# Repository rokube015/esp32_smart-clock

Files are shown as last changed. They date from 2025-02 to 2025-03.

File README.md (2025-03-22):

# ESP32-smart-clock

This repository provides firmware and PCB design for a clock with environmental monitoring project using the ESP-IDF framework.

## Features
- CO2, temperature, humidity and atmosphere pressure monitoring.
- Custom PCB design for the project.
  
 
## Prerequisites

### Software Requirements
- ESP-IDF version 5.3.1 or later
- Python 3.x
## Setup
1. **Install ESP-IDF**: Follow the [ESP-IDF Getting Started Guide](https://docs.espressif.com/projects/esp-idf/en/latest/esp32/get-started/index.html).
2. **Clone the Repository**:
   ```bash
   git clone https://github.com/rokube015/esp32_smart-clock.git
## License
This project is licensed under the [Apache License 2.0](./LICENSE).

### Third-Party Licenses

This project utilizes the following third-party libraries:

- **[ESP-IDF](https://github.com/espressif/esp-idf)** - Licensed under the Apache License 2.0
- **[FreeRTOS](https://github.com/FreeRTOS/FreeRTOS)** - Licensed under the MIT License
- **[LovyanGFX](https://github.com/lovyan03/LovyanGFX)** - Licensed under the MIT License

Each library is subject to its own license terms. Please refer to the respective repositories for more information.
## Contributing
Contributions are welcome!
Please use the Issues tab to report bugs or suggest features, and feel free to submit pull requests.

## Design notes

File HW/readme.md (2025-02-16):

# Hardware Information

This folder contains PCB design files for the ESP32 Smart Clock.

## PCB Folder
The `PCB/` folder contains KiCad project files for the ESP32 Smart Clock.

## Files Description
- **PCB_layout.pdf**: PCB design layout.
- **schematic.pdf**: Circuit schematic diagram.
- **Bom.csv**: List of components required to build the SmartClock.

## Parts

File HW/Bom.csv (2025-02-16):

Reference | Value | Datasheet | Footprint | Qty | DNP
C1,C5 | 10uF | ~ | Capacitor_SMD:C_0603_1608Metric_Pad1.08x0.95mm_HandSolder | 2
C2,C12 | 22uF | ~ | Capacitor_SMD:C_0603_1608Metric_Pad1.08x0.95mm_HandSolder | 2
C3,C13,C15,C16,C18,C19,C20,C21 | 4.7uF | ~ | Capacitor_SMD:C_0603_1608Metric_Pad1.08x0.95mm_HandSolder | 8
C4 | 0.1uF | ~ | Capacitor_SMD:C_0805_2012Metric_Pad1.18x1.45mm_HandSolder | 1
C6,C11 | 0.01uF | ~ | Capacitor_SMD:C_0603_1608Metric_Pad1.08x0.95mm_HandSolder | 2
C7,C8 | 15pF | ~ | Capacitor_SMD:C_0603_1608Metric_Pad1.08x0.95mm_HandSolder | 2
C9,C10,C17,C22 | 1uF | ~ | Capacitor_SMD:C_0603_1608Metric_Pad1.08x0.95mm_HandSolder | 4
D1,D5,D6 | LED | ~ | LED_SMD:LED_0603_1608Metric_Pad1.05x0.95mm_HandSolder | 3
D2,D3,D7,D8,D9 | RB161MM-20 | ~ | Diode_SMD:D_SOD-123 | 5
J1 | USB4105-GF-A | https://www.usb.org/sites/default/files/documents/usb_type-c.zip | mylib:USB-C31-S-VT-CS4-BK-PP-TR | 1
J4 | Micro_SD_Card_Det_Hirose_DM3AT | https://www.hirose.com/product/en/download_file/key_name/DM3/category/Catalog/doc_file_id/49662/?item_id=195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 | Connector_Card:microSD_HC_Hirose_DM3AT-SF-PEJM5 | 1
L1 | 10uH | ~ | mylib:AMP10420ED | 1
Q2 | SI1308EDL-T1-GE3 | https://www.onsemi.com/pub/Collateral/BSS138-D.PDF | Package_TO_SOT_SMD:SOT-323_SC-70_Handsoldering | 1
R1,R2 | 5.1K | ~ | Resistor_SMD:R_1206_3216Metric_Pad1.30x1.75mm_HandSolder | 2
R3 | 0.47 | ~ | Resistor_SMD:R_1206_3216Metric_Pad1.30x1.75mm_HandSolder | 1
R4,R5,R7,R9,R10,R11,R14,R15 | 10K | ~ | Resistor_SMD:R_1206_3216Metric_Pad1.30x1.75mm_HandSolder | 8
R6 | 3 | ~ | Resistor_SMD:R_1206_3216Metric_Pad1.30x1.75mm_HandSolder | 1
R8 | 50K | ~ | Resistor_SMD:R_1206_3216Metric_Pad1.30x1.75mm_HandSolder | 1
SW1 | ssss213202 | ~ | mylib:SSSS213202 | 1
SW2,SW3,SW4 | SKRPACE010 | ~ | mylib:SKRPACE010 | 3
TP1,TP11 | GND | ~ | TestPoint:TestPoint_THTPad_1.0x1.0mm_Drill0.5mm | 2
TP2 | BUSY | ~ | TestPoint:TestPoint_THTPad_D1.0mm_Drill0.5mm | 1
TP3 | RST | ~ | TestPoint:TestPoint_THTPad_D1.0mm_Drill0.5mm | 1
TP4 | D/C | ~ | TestPoint:TestPoint_THTPad_D1.0mm_Drill0.5mm | 1
TP5 | CS | ~ | TestPoint:TestPoint_THTPad_D1.0mm_Drill0.5mm | 1
TP6 | SCK | ~ | TestPoint:TestPoint_THTPad_D1.0mm_Drill0.5mm | 1
TP7 | MOSI | ~ | TestPoint:TestPoint_THTPad_D1.0mm_Drill0.5mm | 1
TP8 | SCL | ~ | TestPoint:TestPoint_THTPad_D1.0mm_Drill0.5mm | 1
TP9 | SDA | ~ | TestPoint:TestPoint_THTPad_D1.0mm_Drill0.5mm | 1
TP10 | 3V3 | ~ | TestPoint:TestPoint_THTPad_D1.0mm_Drill0.5mm | 1
U1 | BME280 |  | mylib:BME280_SwitchScience | 1
U2 | E-Paper 4.26inch, 800x480 | https://www.waveshare.com/4.26inch-e-paper.htm | XF2M-2415-1A:CONN_XF2M-2415-1A_OMR | 1
U4 | ESP32-S3-WROOM-1 | https://www.espressif.com/sites/default/files/documentation/esp32-s3-wroom-1_wroom-1u_datasheet_en.pdf | mylib:ESP32-S3-WROOM-1 | 1
U5 | SCD40 |  | mylib:SCD40_Conta | 1
U6 | AZ1117CH-3_3TRG1 |  | Package_TO_SOT_SMD:SOT-223 | 1
U7 | TPS2065DDBVR | TPS2065DDBVR | Package_TO_SOT_SMD:SOT-23-5 | 1
Y1 | FC-135 | ~ | mylib:FC-135 | 1
- | Card stand | https://www.amazon.co.jp/gp/product/B0BGGFBQXZ/ref=ppx_yo_dt_b_search_asin_title?ie=UTF8&psc=1 | - | 1
- | Thermal Conductive Silicone Pads | https://www.amazon.co.jp/gp/product/B07RW81T8W/ref=ppx_yo_dt_b_search_asin_title?ie=UTF8&th=1 | - | 1

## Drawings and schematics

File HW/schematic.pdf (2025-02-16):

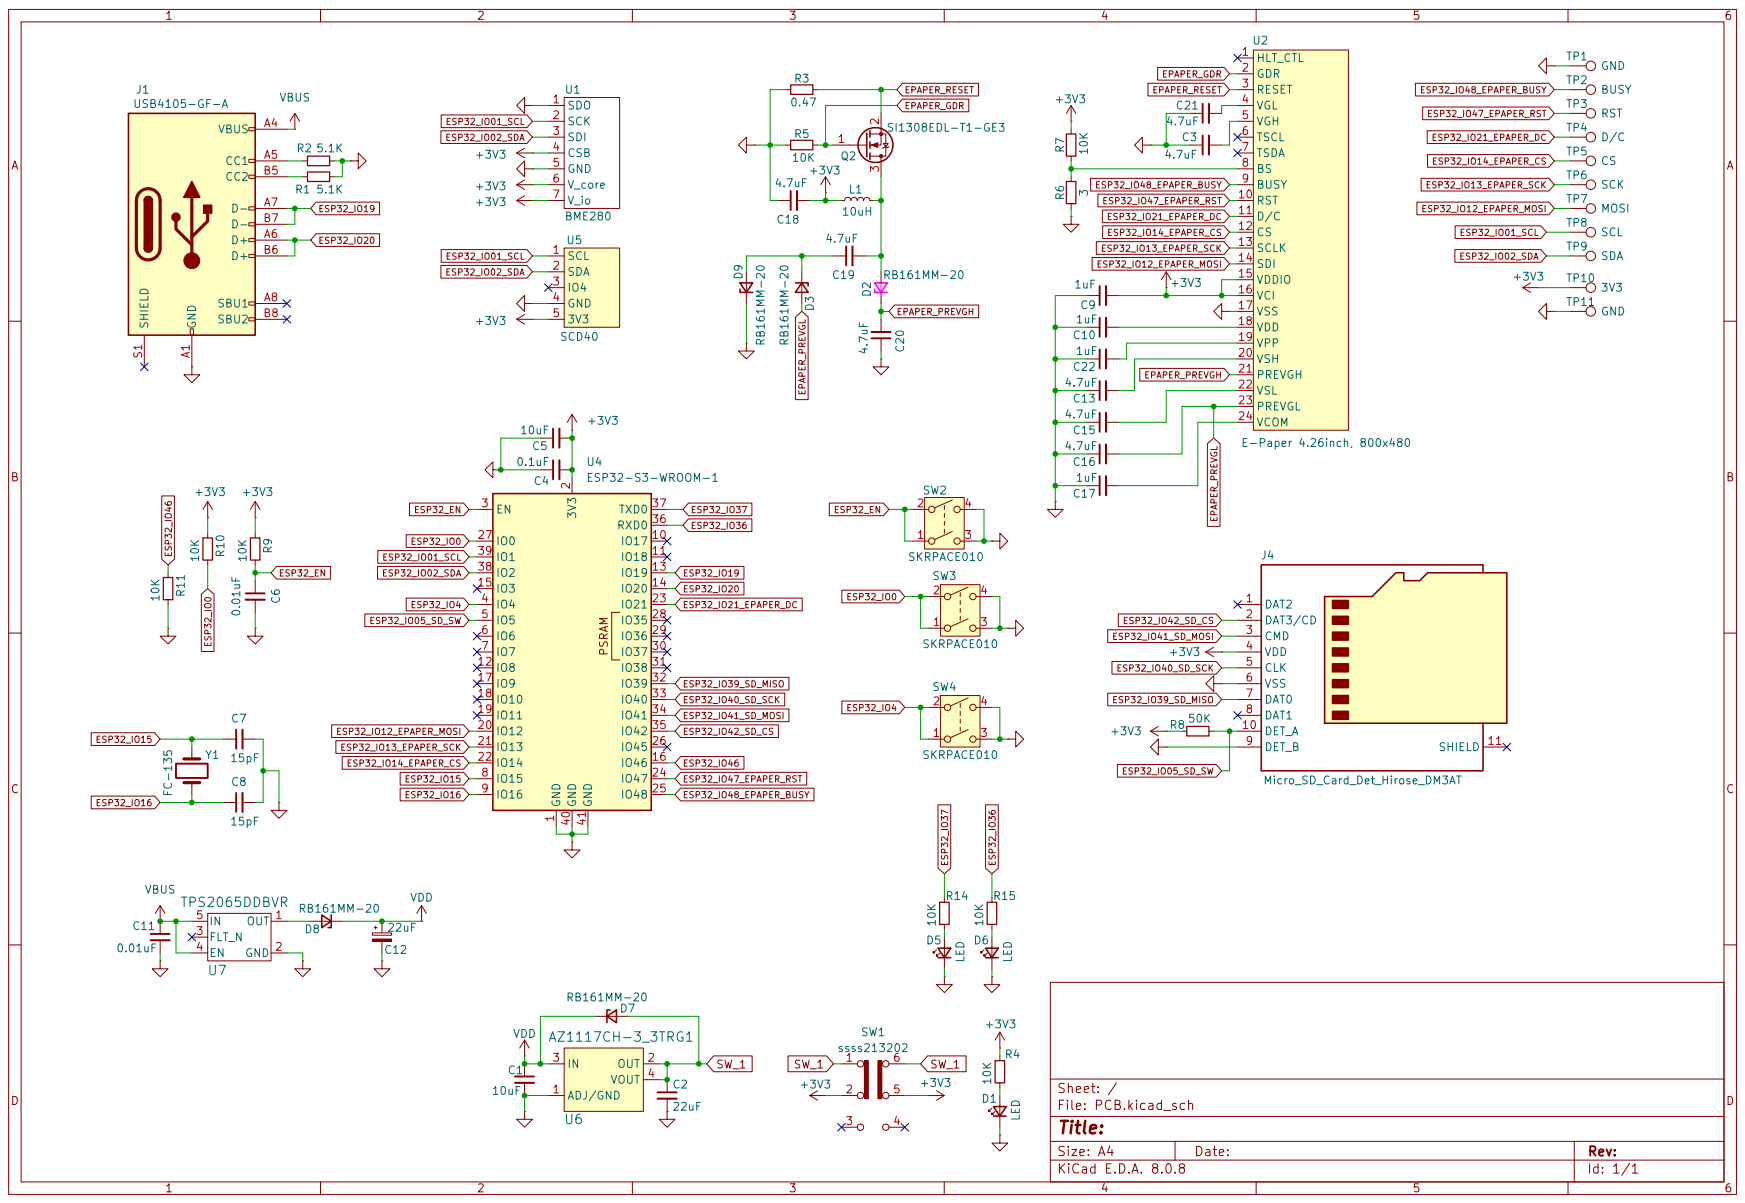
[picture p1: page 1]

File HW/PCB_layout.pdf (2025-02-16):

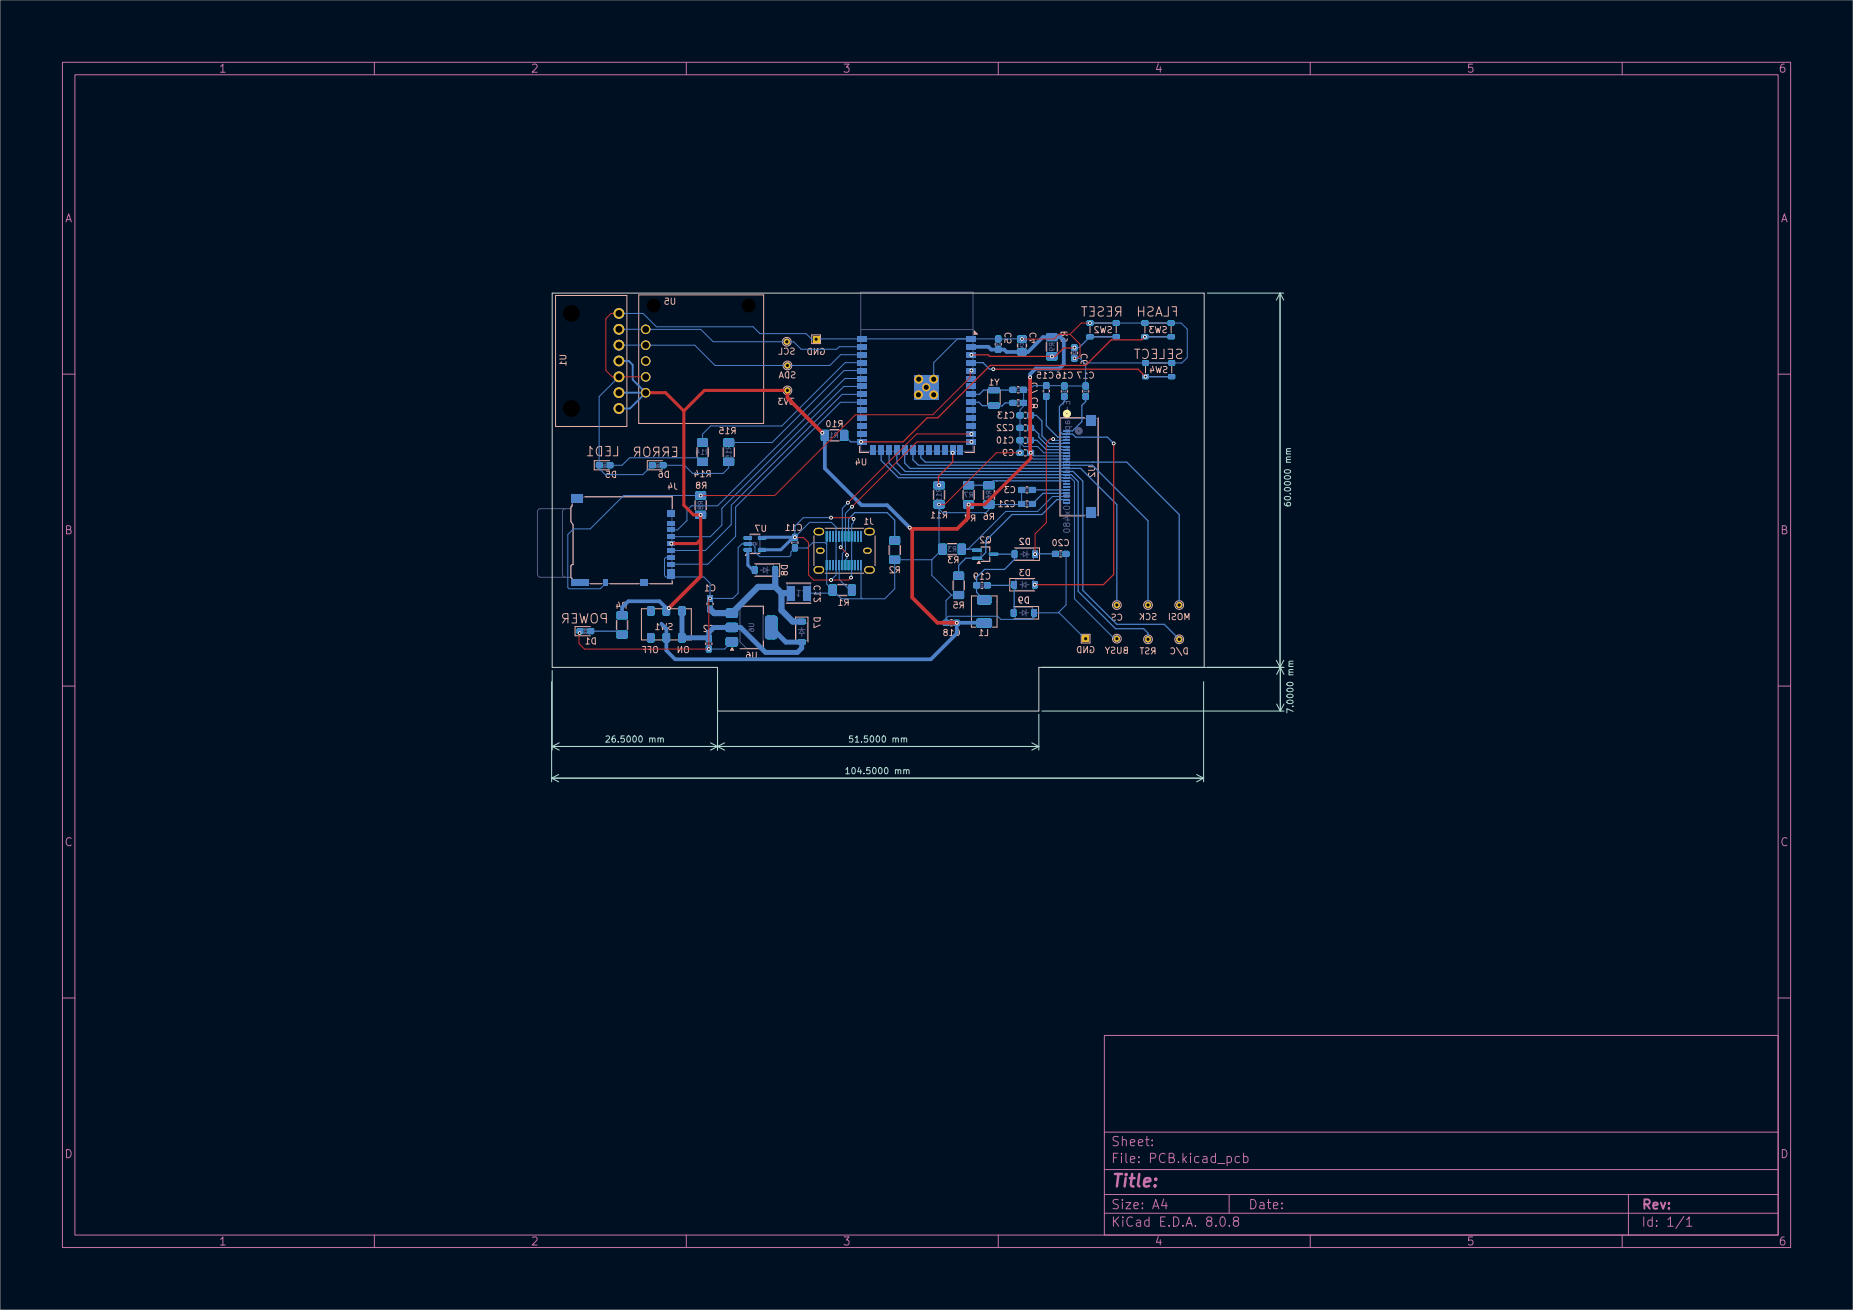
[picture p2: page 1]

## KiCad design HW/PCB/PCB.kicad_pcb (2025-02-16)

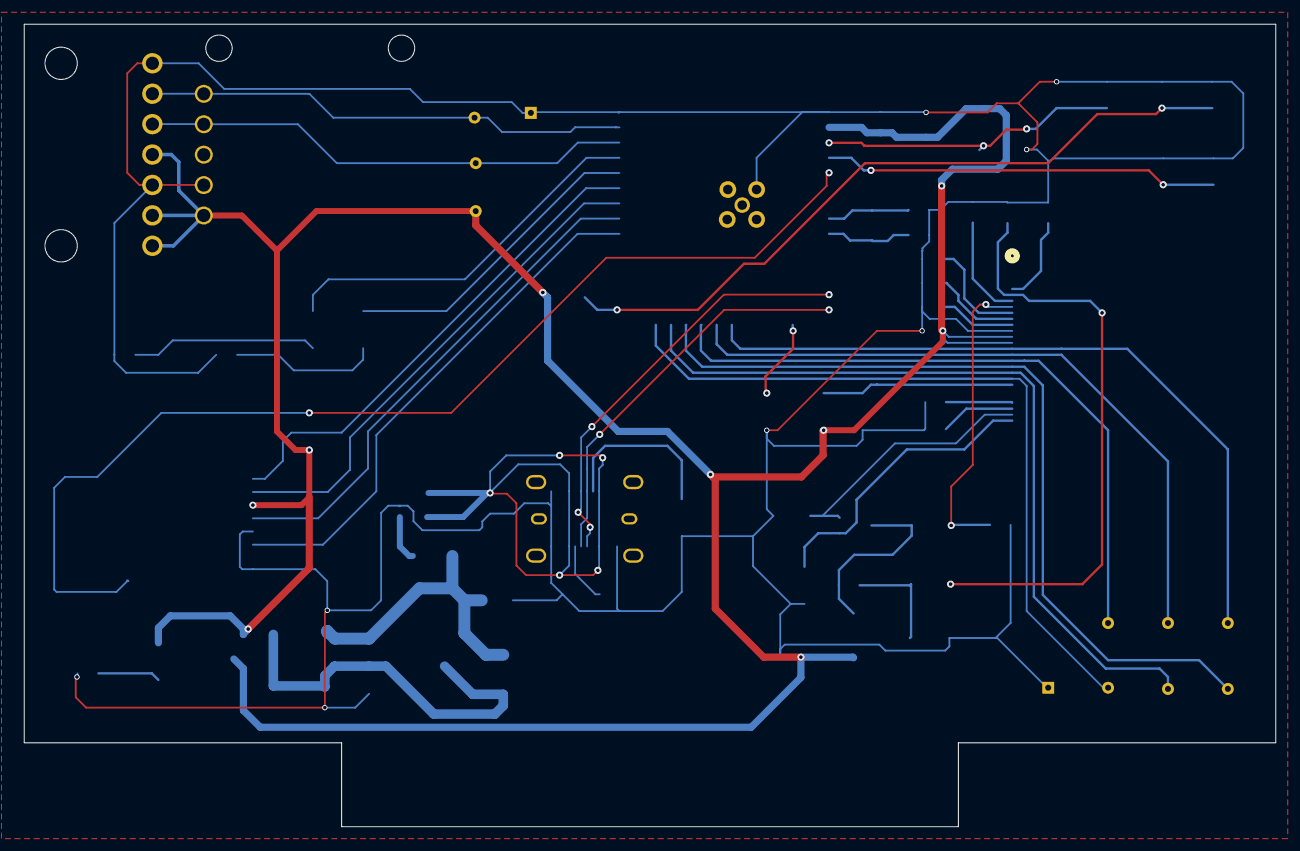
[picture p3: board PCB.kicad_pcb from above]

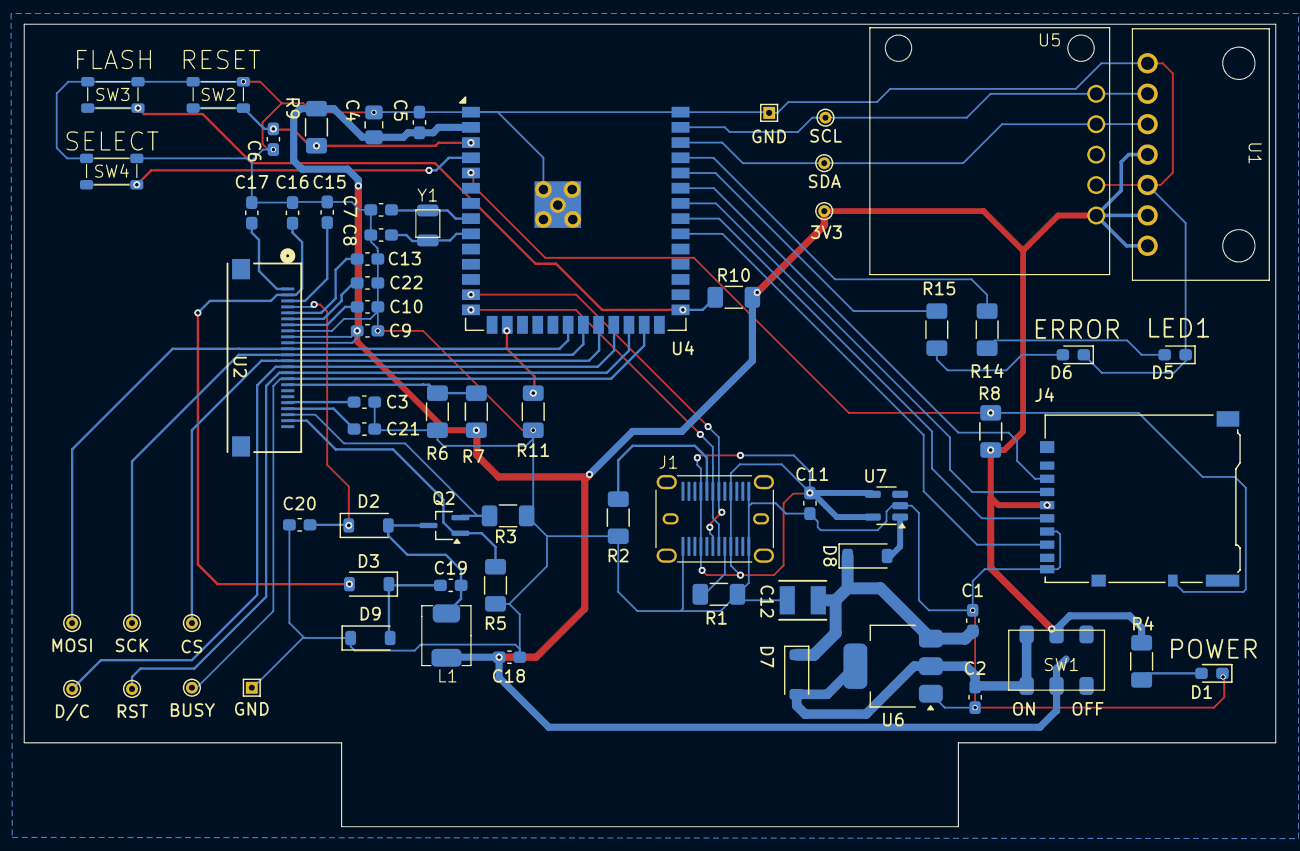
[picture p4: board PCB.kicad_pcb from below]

Board: 2 copper layers, 104.5 x 67.0 mm, 68 parts (68 on the bottom side), 48 nets.

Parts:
C1, C5: 10uF; C_0603_1608Metric_Pad1.08x0.95mm_HandSolder
C2: 22uF; C_0603_1608Metric_Pad1.08x0.95mm_HandSolder
C3, C13, C15, C16, C18, C19, C20, C21: 4.7uF; C_0603_1608Metric_Pad1.08x0.95mm_HandSolder
C4: 0.1uF; C_0805_2012Metric_Pad1.18x1.45mm_HandSolder
C6, C11: 0.01uF; C_0603_1608Metric_Pad1.08x0.95mm_HandSolder
C7, C8: 15pF; C_0603_1608Metric_Pad1.08x0.95mm_HandSolder
C9, C10, C17, C22: 1uF; C_0603_1608Metric_Pad1.08x0.95mm_HandSolder
C12: 22uF; TAJB_AVX
D1, D5, D6: LED; LED_0603_1608Metric_Pad1.05x0.95mm_HandSolder
D2, D3, D7, D8, D9: RB161MM-20; D_SOD-123
J1: USB4105-GF-A; USB-C31-S-VT-CS4-BK-PP-TR
J4: Micro_SD_Card_Det_Hirose_DM3AT; microSD_HC_Hirose_DM3AT-SF-PEJM5
L1: 10uH; AMP10420ED
Q2: SI1308EDL-T1-GE3; SOT-323_SC-70_Handsoldering
R1, R2: 5.1K; R_1206_3216Metric_Pad1.30x1.75mm_HandSolder
R3: 0.47; R_1206_3216Metric_Pad1.30x1.75mm_HandSolder
R4, R5, R7, R9, R10, R11, R14, R15: 10K; R_1206_3216Metric_Pad1.30x1.75mm_HandSolder
R6: 3; R_1206_3216Metric_Pad1.30x1.75mm_HandSolder
R8: 50K; R_1206_3216Metric_Pad1.30x1.75mm_HandSolder
SW1: ssss213202; SSSS213202
SW2, SW3, SW4: SKRPACE010
TP1, TP11: GND; TestPoint_THTPad_1.0x1.0mm_Drill0.5mm
TP2: BUSY; TestPoint_THTPad_D1.0mm_Drill0.5mm
TP3: RST; TestPoint_THTPad_D1.0mm_Drill0.5mm
TP4: D/C; TestPoint_THTPad_D1.0mm_Drill0.5mm
TP5: CS; TestPoint_THTPad_D1.0mm_Drill0.5mm
TP6: SCK; TestPoint_THTPad_D1.0mm_Drill0.5mm
TP7: MOSI; TestPoint_THTPad_D1.0mm_Drill0.5mm
TP8: SCL; TestPoint_THTPad_D1.0mm_Drill0.5mm
TP9: SDA; TestPoint_THTPad_D1.0mm_Drill0.5mm
TP10: 3V3; TestPoint_THTPad_D1.0mm_Drill0.5mm
U1: BME280; BME280_SwitchScience
U2: E-Paper 4.26inch, 800x480; CONN_XF2M-2415-1A_OMR
U4: ESP32-S3-WROOM-1
U5: SCD40; SCD40_Conta
U6: AZ1117CH-3_3TRG1; SOT-223
U7: TPS2065DDBVR; SOT-23-5
Y1: FC-135

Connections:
+3V3: C4.2, C5.2, C9.2, C18.2, J4.4 (VDD), L1.1, R4.2, R7.1, R8.2, R9.2, R10.2, SW1.2 (B), SW1.5 (B), TP10.1, U1.4 (CSB), U1.6 (V_core), U1.7 (V_io), U2.15 (VDDIO), U2.16 (VCI), U4.2 (3V3), U5.5 (3V3)
EPAPER_GDR: Q2.1 (G), R5.1, U2.2 (GDR)
EPAPER_PREVGH: C20.2, D2.1 (K), U2.21 (PREVGH)
EPAPER_PREVGL: C16.2, D3.2 (A), U2.23 (PREVGL)
EPAPER_RESET: Q2.2 (S), R3.1, U2.3 (RESET)
ESP32_EN: C6.1, R9.1, SW2.1, SW2.2, U4.3 (EN)
ESP32_IO0: R10.1, SW3.1, SW3.2, U4.27 (IO0)
ESP32_IO01_SCL: TP8.1, U1.2 (SCK), U4.39 (IO1), U5.1 (SCL)
ESP32_IO02_SDA: TP9.1, U1.3 (SDI), U4.38 (IO2), U5.2 (SDA)
ESP32_IO4: SW4.1, SW4.2, U4.4 (IO4)
ESP32_IO05_SD_SW: J4.10 (DET_A), R8.1, U4.5 (IO5)
ESP32_IO12_EPAPER_MOSI: TP7.1, U2.14 (SDI), U4.20 (IO12)
ESP32_IO13_EPAPER_SCK: TP6.1, U2.13 (SCLK), U4.21 (IO13)
ESP32_IO14_EPAPER_CS: TP5.1, U2.12 (CS), U4.22 (IO14)
ESP32_IO15: C7.1, U4.8 (IO15), Y1.2
ESP32_IO16: C8.1, U4.9 (IO16), Y1.1
ESP32_IO19: J1.A7 (D-), J1.B7 (D-), U4.13 (IO19)
ESP32_IO20: J1.A6 (D+), J1.B6 (D+), U4.14 (IO20)
ESP32_IO21_EPAPER_DC: TP4.1, U2.11 (D/C), U4.23 (IO21)
ESP32_IO36: R15.2, U4.36 (RXD0)
ESP32_IO37: R14.2, U4.37 (TXD0)
ESP32_IO39_SD_MISO: J4.7 (DAT0), U4.32 (IO39)
ESP32_IO40_SD_SCK: J4.5 (CLK), U4.33 (IO40)
ESP32_IO41_SD_MOSI: J4.3 (CMD), U4.34 (IO41)
ESP32_IO42_SD_CS: J4.2 (DAT3/CD), U4.35 (IO42)
ESP32_IO46: R11.2, U4.16 (IO46)
ESP32_IO47_EPAPER_RST: TP3.1, U2.10 (RST), U4.24 (IO47)
ESP32_IO48_EPAPER_BUSY: TP2.1, U2.9 (BUSY), U4.25 (IO48)
GND: C1.2, C2.2, C3.1, C4.1, C5.1, C6.2, C7.2, C8.2, C9.1, C10.1, C11.2, C12.2, C13.1, C15.1, C16.1, C17.1, C18.1, C20.1, C21.1, C22.1, D1.1 (K), D5.1 (K), D6.1 (K), D9.1 (K), J1.A12 (GND), J1.B1 (GND), J1.B12 (GND), J4.6 (VSS), J4.9 (DET_B), R1.2, R2.2, R3.2, R5.2, R6.1, R11.1, SW2.3, SW2.4, SW3.3, SW3.4, SW4.3, SW4.4, TP1.1, TP11.1, U1.1 (SDO), U1.5 (GND), U2.17 (VSS), U4.1 (GND), U4.40 (GND), U4.41 (GND), U5.4 (GND), U6.1 (ADJ/GND), U7.2 (GND)
unnamed: D1.2 (A), R4.1
unnamed: C19.2, D2.2 (A), L1.2, Q2.3 (D)
unnamed: C19.1, D3.1 (K), D9.2 (A)
unnamed: D5.2 (A), R14.1
unnamed: D6.2 (A), R15.1
unnamed: D8.2 (A), U7.1 (OUT)
unnamed: J1.A5 (CC1), R2.1
unnamed: J1.B5 (CC2), R1.1
unnamed: R6.2, R7.2, U2.8 (BS)
unnamed: C17.2, U2.24 (VCOM)
unnamed: C10.2, U2.18 (VDD)
unnamed: C3.2, U2.5 (VGH)
unnamed: C21.2, U2.4 (VGL)
unnamed: C22.2, U2.19 (VPP)
unnamed: C13.2, U2.20 (VSH)
unnamed: C15.2, U2.22 (VSL)
SW_1: C2.1, D7.2 (A), SW1.1 (A), SW1.6 (C), U6.2 (OUT), U6.4 (VOUT)
VBUS: C11.1, J1.A4 (VBUS), J1.A9 (VBUS), J1.B4 (VBUS), J1.B9 (VBUS), U7.4 (EN), U7.5 (IN)
VDD: C1.1, C12.1, D7.1 (K), D8.1 (K), U6.3 (IN)

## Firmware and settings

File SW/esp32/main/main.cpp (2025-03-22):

#include <iostream>

#include "smart_clock.h"

static const char* MAIN_TAG = "main";

extern "C" void app_main(void){ 
  esp_log_level_set(MAIN_TAG, ESP_LOG_INFO); 
  esp_err_t r = ESP_OK;  
  ESP_LOGI(MAIN_TAG, "Start main"); 
  SMART_CLOCK smart_clock; 
  if(r == ESP_OK){ 
    r = smart_clock.init();
    if(r != ESP_OK){
      ESP_LOGE(MAIN_TAG, "fail to initialize smart_clock.");
    }
  }
  if(r == ESP_OK){ 
    smart_clock.wifi_run();
  }
  if(r == ESP_OK){ 
    r = smart_clock.run();
    if(r != ESP_OK){
      ESP_LOGE(MAIN_TAG, "fail to run smart_clock.");
    }
  }
  while(true){
    smart_clock.wifi_run();
    vTaskDelay(pdMS_TO_TICKS(30*1000));
  }
}

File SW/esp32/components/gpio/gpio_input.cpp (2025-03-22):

#include "gpio_interface.h"

namespace GpioInterface{ 
  bool GpioInput::minterrupt_service_installed{false};
  portMUX_TYPE GpioInput::mevent_change_mutex = portMUX_INITIALIZER_UNLOCKED;

  ESP_EVENT_DEFINE_BASE(INPUT_EVENTS);

  void IRAM_ATTR GpioInput::gpio_isr_callback(void *args){
    int32_t pin = (reinterpret_cast<interrupt_args_t*>(args))->mpin;
    bool custom_event_handler_set = (reinterpret_cast<interrupt_args_t*>(args))->mcustom_event_handler_set;
    bool event_handler_set = 
      (reinterpret_cast<interrupt_args_t*>(args))->mevent_handler_set;
    bool queue_enabled = 
      (reinterpret_cast<interrupt_args_t*>(args))->mqueue_enable;
    esp_event_loop_handle_t custom_event_loop_handle = 
      (reinterpret_cast<interrupt_args_t*>(args))->mcustom_event_loop_handle;
    QueueHandle_t queue_handle = 
      (reinterpret_cast<interrupt_args_t*>(args))->mqueue_handle;

    if(queue_enabled){
      xQueueSendFromISR(queue_handle, &pin, NULL);
    }
    else if(custom_event_handler_set){
      esp_event_isr_post_to(custom_event_loop_handle, INPUT_EVENTS, pin, nullptr, 0, nullptr);
    }
    else if(event_handler_set){
      esp_event_isr_post(INPUT_EVENTS, pin, nullptr, 0, nullptr);
    }

    esp_event_isr_post(INPUT_EVENTS, pin, nullptr, 0, nullptr);
  }

  esp_err_t GpioInput::minit(const gpio_num_t pin, const bool activeLow){
    esp_err_t r = ESP_OK;

    mactive_low = activeLow;
    minterrupt_args.mpin = pin;

    gpio_config_t cfg;
    cfg.pin_bit_mask = 1ULL << pin;
    cfg.mode = GPIO_MODE_INPUT;
    cfg.pull_up_en = GPIO_PULLUP_DISABLE;
    cfg.pull_down_en = GPIO_PULLDOWN_DISABLE;
    cfg.intr_type = GPIO_INTR_DISABLE;

    r = gpio_config(&cfg);

    return r;
  }

  GpioInput::GpioInput(const gpio_num_t pin, const bool active_low){
    minit(pin, active_low);
  }

  GpioInput::GpioInput(const gpio_num_t pin){
    minit(pin, false);
  }

  GpioInput::GpioInput(void){

  }

  esp_err_t GpioInput::init(const gpio_num_t pin, const bool active_low){
    return minit(pin, active_low);
  }

  esp_err_t GpioInput::init(const gpio_num_t pin){
    return minit(pin, false);
  }

  int GpioInput::read(void){
    int gpio_level = gpio_get_level(minterrupt_args.mpin);
    gpio_level = (mactive_low ? !gpio_level : gpio_level);
    ESP_LOGD(GPIO_TAG, "read gpio %d pin: %d, active_low: %d", 
        minterrupt_args.mpin, gpio_level, mactive_low);
    return gpio_level;
  }

  esp_err_t GpioInput::enable_pull_up(void){
    return gpio_set_pull_mode(minterrupt_args.mpin, GPIO_PULLUP_ONLY);
  }

  esp_err_t GpioInput::disable_pull_up(void){
    return gpio_set_pull_mode(minterrupt_args.mpin, GPIO_FLOATING);
  }

  esp_err_t GpioInput::enable_pull_down(void){
    return gpio_set_pull_mode(minterrupt_args.mpin, GPIO_PULLDOWN_ONLY);
  }

  esp_err_t GpioInput::disable_pull_down(void){
    return gpio_set_pull_mode(minterrupt_args.mpin, GPIO_FLOATING);
  }

  esp_err_t GpioInput::enable_pull_up_and_pull_down(void){
    return gpio_set_pull_mode(minterrupt_args.mpin, GPIO_PULLUP_PULLDOWN);
  }

  esp_err_t GpioInput::disable_pull_up_and_pull_down(void){
    return gpio_set_pull_mode(minterrupt_args.mpin, GPIO_FLOATING);
  }

  esp_err_t GpioInput::enable_interrupt(gpio_int_type_t int_type){
    esp_err_t r = ESP_OK;

    // Invert triggers if active low is enabled
    if(mactive_low){
      switch(int_type){
        case GPIO_INTR_POSEDGE:
          int_type = GPIO_INTR_NEGEDGE;
          break;
        case GPIO_INTR_NEGEDGE:
          int_type = GPIO_INTR_POSEDGE;
          break;
        case GPIO_INTR_LOW_LEVEL:
          int_type = GPIO_INTR_HIGH_LEVEL;
          break;
        case GPIO_INTR_HIGH_LEVEL:
          int_type = GPIO_INTR_LOW_LEVEL;
          break;
        default:
          break;
      }
    }

    if(!minterrupt_service_installed){
      r = gpio_install_isr_service(0);
      if(r == ESP_OK){
        minterrupt_service_installed = true;
      }
    }

    if(r == ESP_OK){
      r = gpio_set_intr_type(minterrupt_args.mpin, int_type);
    }

    if(r == ESP_OK){
      r = gpio_isr_handler_add(minterrupt_args.mpin, gpio_isr_callback, (void *)&minterrupt_args);
    }
    return r;
  }

  esp_err_t GpioInput::set_event_handler(esp_event_handler_t Gpio_e_h){
    esp_err_t r = ESP_OK;
    
    taskENTER_CRITICAL(&mevent_change_mutex);
    
    r = mclear_event_handlers();
    
    r |= esp_event_handler_instance_register(INPUT_EVENTS, minterrupt_args.mpin, Gpio_e_h, 0, nullptr);

    if(r == ESP_OK){
      mevent_handler_set = true;
    }

    taskENTER_CRITICAL(&mevent_change_mutex);

    return r;
  }

  esp_err_t GpioInput::set_event_handler(esp_event_loop_handle_t Gpio_e_l, esp_event_handler_t Gpio_e_h){
    esp_err_t r = ESP_OK;
    taskENTER_CRITICAL(&mevent_change_mutex);

    r = mclear_event_handlers();
    r |= esp_event_handler_instance_register_with(Gpio_e_l, INPUT_EVENTS, minterrupt_args.mpin, Gpio_e_h, 0, nullptr);
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

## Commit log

2024-07-21 add esp32 file
2024-08-31 Add read CO2, humidity adn temperature from scd40
2024-08-31 Remove esp32/build directory
2024-08-31 Remove esp32/main/build directory
2024-09-08 Add function for set temperature offset on scd40.
2024-09-15 add set temperature offset function
2024-09-22 modify output log for sensor data
2024-09-29 add bme280 sensor read function
2024-09-29 add HW file for PCB
    [PCB.kicad_pcb, PCB.kicad_sch]
2024-10-13 add kicad data
    [PCB.kicad_pcb, PCB.kicad_sch]
2024-11-09 Add PCB layout
    [PCB.kicad_pcb]
2024-11-09 add schematic file
    [PCB.kicad_pcb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]
2024-11-30 modify PCB layout
    [PCB.kicad_pcb, PCB.kicad_sch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]
2024-12-01 change project/esp32 file name to projecr/SW
2024-12-01 add i2c_base component
2024-12-08 modify i2c interface for using new i2c esp-idf lib.
2024-12-08 modify i2c interface function
2024-12-14 add gaber data
    [PCB-B_Cu.GBL, PCB-B_Mask.GBS, PCB-B_Silkscreen.GBO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]
2024-12-14 add PMIC
    [PCB.kicad_pcb, PCB.kicad_sch]
2024-12-15 modify PCB design pattern
    [PCB.kicad_pcb, PCB.kicad_sch]
2024-12-20 add guber date
    [PCB.GBL, PCB.GBO, PCB.GBS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]
2024-12-28 add to sensor data write function
2024-12-28 change pressure output format from Pa to hPa.
2024-12-29 change target SoC to ESP32-S3 from ESP32
2024-12-29 change i2c port settings
2024-12-30 add i2c_port_mutex
2024-12-31 add measure bme280 sensor data task.
2025-02-02 add e-paper module
    [PCB.kicad_pcb, PCB.kicad_sch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]
2025-02-02 add epaper components
    [partitions.csv]
2025-02-15 modify schematics
    [PCB.kicad_pcb, PCB.kicad_sch]
2025-02-16 Order HW/PCB/ESP32_SmartClock_GBR_ELECROW.zip to Elecrow (#243165)
    [PCB.kicad_pcb]
2025-02-16 add Bom fail
    [Bom.csv]
2025-02-16 add kicad symbol file.
2025-02-22 add doxygen comment in i2c_base.h
2026-10-10 Add Wi-Fi provisioning and power management
2026-10-10 Fix sensor logging, recovery, and startup concurrency
2026-10-11 Refactor clock sensor pipeline and add Android sensor client
